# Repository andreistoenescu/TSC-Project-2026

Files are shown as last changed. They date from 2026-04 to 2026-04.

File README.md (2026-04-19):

# Watch_TSC_Project

Un smartwatch construit de la zero — schematic, PCB 4 straturi, carcasă 3D — centrat pe nRF52840 și un display E-Paper care nu consumă energie când nu se schimbă nimic pe ecran.

---

## Ce este acest proiect

Scopul a fost să proiectez un ceas inteligent complet: de la primul simbol în schematic până la modelul 3D gata de imprimat. Nu un modul dev board montat într-o carcasă, ci un PCB custom cu toate componentele alese și integrate manual.

Tehnologia cheie este display-ul **E-Paper (e-ink)** — odată ce afișează ceva, menține imaginea fără niciun consum de curent. Combinat cu modurile deep sleep ale nRF52840 (1.5μA), rezultatul este un dispozitiv care poate rula zile întregi dintr-o celulă LiPo mică.

### Ce integrează placa

| Subsistem | Componentă | Rol |
|---|---|-----|
| Microcontroller | nRF52840 | Cortex-M4 64MHz, BT 5.0, USB nativ |
| Display | E-Paper via SPI | Afișaj zero-consum în standby |
| Mișcare | BMA423 | Accelerometru 3 axe, step counter, wake-on-wrist |
| Încărcare | BQ25180 | LiPo charger programabil I2C, 5mA–1A |
| Alimentare | RT6160 | Buck-Boost 3.3V stabil indiferent de tensiunea bateriei |
| Baterie | MAX17048 | Fuel gauge ModelGauge, fără shunt rezistor |
| Feedback | DRV2605 | Driver haptic, 123 efecte ERM/LRA |
| USB | KH-TYPE-C-16P + USBLC6 | Conector C16P cu protecție ESD ±15kV |
| Input | EVP-AKE31A ×3 | Butoane tactile SMD ultra-subțiri |
| RF | 2450AT18B100E | Antenă SMD 2.45GHz pentru Bluetooth |

---

## Diagrama bloc a sistemului

```
  USB-C (5V)
      │
      ▼
 ┌─────────┐    VBUS      ┌──────────────┐
 │  ESD    │─────────────▶│  BQ25180     │ LiPo Charger
 │USBLC6   │              │  (I2C 0x6A)  │◀─── Baterie LiPo
 └────┬────┘              └──────┬───────┘
      │ D+/D−                    │ VBAT
      │                          ▼
      │                   ┌──────────────┐
      │                   │  MAX17048    │ Fuel Gauge
      │                   │  (I2C 0x36)  │
      │                   └──────┬───────┘
      │                          │ VBAT
      │                          ▼
      │                   ┌──────────────┐
      │                   │   RT6160     │ Buck-Boost DC/DC
      │                   │  (I2C 0x62)  │─── 3V3 ───────────┐
      │                   └──────────────┘                    │
      │                                                       │
      └───────────────────────────────────────────────────────▼
                                                     ┌─────────────────┐
                    ┌── SPI ──▶ E-Paper Display       │                 │
                    │                                 │   nRF52840      │
                    ├── I2C ──▶ BMA423  (0x18)        │   Cortex-M4     │
                    │       ──▶ DRV2605 (0x5A)        │   64MHz / BT5.0 │
                    │       ──▶ BQ25180 (0x6A)        │                 │
                    │       ──▶ RT6160  (0x62)        └────────┬────────┘
                    │       ──▶ MAX17048(0x36)                 │
                    │                                          │ GPIO
                    ├── SWD ──▶ TC2030-IDC                     │
                    │                                          ▼
                    └── USB ──▶ (intern nRF52840)      Butoane ×3 / IMU INT / HAPTIC_EN
```

---

## Componente — BOM complet

| Ref | Part Number | Descriere | Qty |
|-----|---|---|:---:|
| U1 | nRF52840-QIAA | MCU ARM Cortex-M4, BT 5.0, USB 2.0, 1MB Flash | 1 |
| IC1 | BQ25180YBGR | LiPo charger liniar 1A I2C, 8-DSBGA | 1 |
| IC2 | DRV2605YZFR | Haptic driver ERM/LRA I2C 123 efecte, 9-BGA | 1 |
| IC3 | BMA423 | Accelerometru MEMS triaxial 12-bit, LGA-12 | 1 |
| U3 | MAX17048G+T10 | Fuel gauge ModelGauge 1-cell, SOT-23-6 | 1 |
| IC9 | RT6160AWSC | Buck-Boost DC/DC 800mA I2C, 15-WL-CSP | 1 |
| D3 | USBLC6-2SC6Y | TVS ESD ±15kV bidirecțional USB, SOT-23-6 | 1 |
| J4 | KH-TYPE-C-16P | Conector USB-C 16 pini SMD | 1 |
| J1 | 503480-2400 | Conector FPC/FFC 0.5mm pas 24 circuite | 1 |
| J2 | TC2030-IDC | Tag-Connect SWD 6 pini footprint-only | 1 |
| Q2 | DMG2305UX-7 | P-MOSFET 20V/4.2A, SOT-23 | 1 |
| Q3 | SI1308EDL-T1-GE3 | N-MOSFET 30V/1.5A, SC-70 | 1 |
| D1,D2,D5 | MBR0530 | Schottky 30V/500mA, SOD-123 | 3 |
| SW_* | EVP-AKE31A | Buton tactil SMD ultra-subțire Panasonic | 3 |
| ANT1 | 2450AT18B100E | Antenă SMD 2.45GHz Johanson | 1 |
| L7 | FTC252012SR47MBCA | Inductor 0.47μH SMD 2016 | 1 |
| L5 | 744043680 | Inductor 68μH WE-TPC SMD | 1 |
| X1 | Crystal 32MHz | Oscilator SMD 32MHz 2016 | 1 |
| X2 | Crystal 32.768kHz | Oscilator RTC 32.768kHz 3215 SMD | 1 |
| Cx | — | Condensatoare SMD 0201/0402, 1pF–22μF | ~50 |
| Rx | — | Rezistoare SMD 0201, 2.2Ω–10kΩ | ~15 |
| Lx | — | Inductoare SMD 0402, 3.9nH–10μH | ~4 |
| TP_* | TP20R | Test pad SMD 2mm | 14 |
| SJ1 | — | Solder jumper SMD | 1 |

---

## Hardware în detaliu

### Cum circulă energia

Bateria LiPo (3.7–4.2V) alimentează regulatorul **RT6160** care produce un 3V3 stabil pentru toată placa. Când e conectat USB-C, VBUS (5V) merge direct la **BQ25180** care preia încărcarea bateriei independent de restul sistemului. nRF52840 monitorizează ambele stări: știe când USB e prezent (CHARGER_PG) și câtă baterie a mai rămas (MAX17048 via I2C).

Componentele cu consum ridicat — display-ul și haptic driver-ul — sunt controlate prin MOSFET-uri (Q2/Q3), astfel că nRF52840 le poate tăia complet alimentarea când nu sunt necesare.

### Magistrala I2C — 5 periferice pe aceleași fire

| Componentă | Adresă I2C | Ce face |
|---|:---:|---|
| BQ25180 | 0x6A | Controlează curentul și tensiunea de încărcare |
| RT6160 | 0x62 | Ajustează tensiunea de ieșire dacă e necesar |
| BMA423 | 0x18 | Livrează date accelerometru, numără pași |
| MAX17048 | 0x36 | Raportează SOC% și tensiunea celulei |
| DRV2605 | 0x5A | Selectează și redă efecte tactile |

Clock pe **P0.06**, date pe **P0.07**. Rezistoare de pull-up pe ambele linii.

### SPI — display E-Paper

Comunicație write-only spre display (nu există linie MISO — displayul nu trimite date înapoi). Frecvență maximă 4MHz. Pe lângă SCK și MOSI, display-ul are nevoie de 3 semnale GPIO suplimentare: DC (Data/Command), RST (reset hardware) și BUSY (ceasul trebuie să aștepte când displayul procesează un refresh).

### SWD — programare și debug

Conectorul **TC2030-IDC** (Tag-Connect, fără pini fizici pe PCB) expune SWDIO, SWDCLK, SWO și RESET. Nu ocupă spațiu vertical în ansamblu — cablul de programare se atașează temporar prin spring pins direct pe pad-urile de pe PCB.

### Bluetooth și antena

Antena **2450AT18B100E** este o antenă SMD ceramică pentru 2.4GHz, plasată în colțul plăcii cu un cutout în substrat sub ea. Cutout-ul elimină FR4-ul (material dielelectric cu pierderi la 2.4GHz) din zona de radiație, îmbunătățind câștigul și SWR-ul antenei. Cristalul de 32MHz asigură referința de frecvență pentru radio.

### Cristalul de 32.768kHz — RTC în sleep

Al doilea oscilator, la 32.768kHz, alimentează timer-ul RTC al nRF52840 și rămâne activ chiar și în deep sleep. Permite ceasului să știe ora exactă și să se trezească la intervale precise fără să țină procesorul pornit.

### BMA423 — mai mult decât un accelerometru

BMA423 are un procesor intern dedicat care rulează algoritmii de step counting și wake-on-wrist fără să implice nRF52840. Când detectează mișcarea caracteristică ridicării mâinii, trimite o întrerupere pe **P1.08 (IMU_INT1)** care trezește MCU-ul din deep sleep în microsecunde. Consum în această stare: **0.9μA**.

### Estimare consum și autonomie

| Scenariu | Curent estimat |
|---|:---:|
| nRF52840 TX Bluetooth activ | 6.26 mA |
| nRF52840 RX Bluetooth activ | 4.82 mA |
| Refresh display E-Paper | ~26 mA (câteva secunde) |
| BMA423 monitorizare continuă | 130 μA |
| MAX17048 fuel gauge activ | 23 μA |
| DRV2605 vibrație activă | 5 mA |
| nRF52840 deep sleep + RTC + BMA low-power | ~50–100 μA |

**Consum mediu în utilizare normală** (BT conectat periodic, display refresh la fiecare minut, IMU activ): **6–8 mA** la 3.3V.

Cu o baterie LiPo de **300mAh**: autonomie estimată **35–50 ore**.

---

## Alocarea pinilor nRF52840

### Display E-Paper (SPI)

| Pin MCU | Semnal | Direcție | Descriere |
|---|---|:---:|---|
| P0.02 / AIN0 | SCK | OUT | Clock SPI pentru display |
| P0.03 / AIN1 | MOSI | OUT | Date seriale spre display |
| P0.05 / AIN3 | EPD_CS | OUT | Chip select, activ LOW |
| P0.15 | EPD_RST | OUT | Reset hardware display, activ LOW |
| P0.16 | EPD_DC | OUT | LOW = comandă, HIGH = date |
| P0.17 | EPD_BUSY | IN | HIGH când displayul procesează |

### Periferice I2C

| Pin MCU | Semnal | Descriere |
|---|---|---|
| P0.06 | SCL | Clock comun pentru toate perifericele I2C |
| P0.07 | SDA | Date bidirecționale I2C |
| P0.08 | IMU_INT2 | Întrerupere secundară BMA423 (step counter) |
| P1.08 | IMU_INT1 | Întrerupere primară BMA423 (wake-on-wrist) |
| P0.10 / NFC2 | FUELGAUGE_ALT | Alarmă MAX17048 la baterie scăzută |
| P0.11 | CHARGER_PG | Power Good BQ25180 — 1 când USB e valid |
| P0.12 | HAPTIC_EN | Enable DRV2605, activ HIGH |

### Butoane și control

| Pin MCU | Semnal | Descriere |
|---|---|---|
| P0.13 | BTN_UP | Buton sus (navigare meniu) |
| P0.14 | BTN_ENT | Buton enter / confirmare |
| P1.02 | BTN_DN | Buton jos (navigare meniu) |

### USB, SWD și ceasuri

| Pin MCU | Semnal | Interfață | Descriere |
|---|---|:---:|---|
| D+ | USB_DP | USB | Linie diferențială pozitivă, prin ESD |
| D− | USB_DM | USB | Linie diferențială negativă, prin ESD |
| VBUS | 5V_USB | PWR | Detecție USB prezent → BQ25180 |
| SWDIO | SWDIO | SWD | Date programare/debug |
| SWDCLK | SWDCLK | SWD | Clock programare/debug |
| SWO | SWO | SWD | Serial Wire Output (trace) |
| P0.18 / RESET | RESET | GPIO | Reset hardware MCU |
| ANT | RF | RF | Antenă Bluetooth 2.4GHz |
| XC1, XC2 | XTAL_32M | CLK | Cristal 32MHz — clock principal |
| XL1, XL2 | XTAL_32K | CLK | Cristal 32.768kHz — RTC sleep |

---

## PCB — decizii de proiectare

### 4 straturi: de ce și cum

| Strat | Conținut |
|---|---|
| **L1 — Top** | Toate componentele SMD + rutare semnale principale |
| **L2** | Plan de masă GND continuu |
| **L3** | Plan de alimentare 3V3 |
| **L4 — Bottom** | Rutare secundară + via connections |

Planul de masă pe L2 direct sub stratul de semnal L1 minimizează inductanța buclei de return pentru fiecare traseu. Fără acest plan, semnalele SPI și I2C ar genera mai mult EMI și ar fi mai sensibile la zgomot. Planul de 3V3 pe L3 reduce impedanța de alimentare, esențial pentru vârfurile de curent ale nRF52840 în TX.

### Via-in-pad

BQ25180, RT6160, DRV2605 și MAX17048 vin în packaging BGA/CSP cu pitch sub 0.5mm — imposibil de rutat cu via-uri laterale în spațiul disponibil. Soluția: via-uri plasate direct în centrul pad-urilor BGA. Acestea trebuie **umplute cu rășină epoxidică și planarize** (filled & capped) înainte de HASL/ENIG, altfel pasta de lipit curge în via și jointul devine defectuos.

### Cutout sub antenă

Substatul FR4 este un material cu pierderi dielectrice la 2.4GHz. Lăsat sub zona de radiație a antenei 2450AT18B100E, absoarbe o parte din energia RF și detune antena față de 50Ω. Soluția: un decupaj fizic al PCB-ului sub jumătatea neconectată a antenei, astfel că aceasta radiază în aer.

### 14 test pad-uri TP20R

Distribuite pe semnalele: 3V3, VBAT, GND, SDA, SCL, SWDCLK, SWDIO, SWO, RESET, VREG. Permit conectarea unui multimetru sau logicanalyzer după asamblare fără a fi nevoie de probe pe QFN/BGA.

---

## Ansamblu 3D

Modelat complet în **Autodesk Fusion 360**. Ansamblul verifică că totul se potrivește fizic înainte de fabricație.

Stratificarea de jos în sus:

```
  ┌─────────────────────────┐  ← Cadru superior + geam display
  │     Display E-Paper     │  ← Panou e-ink + cablu FPC
  │         PCB             │  ← Placa cu toate componentele
  │      Baterie LiPo       │  ← Celulă cu fire sudate pe test pads
  └─────────────────────────┘  ← Carcasă inferioară
```

Butoanele (×3) sunt accesibile prin locașuri în carcasa inferioară, pe laterale. Conectorul USB-C iese prin fanta frontală a carcasei. Shaker-ul haptic este montat cilindric în spațiul rămas lângă baterie.

---

## Galerie

### PCB — Layout 2D
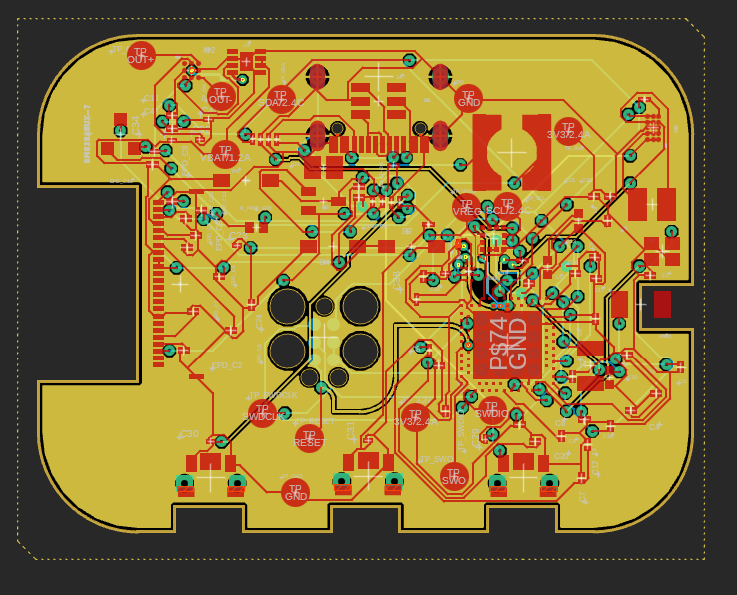
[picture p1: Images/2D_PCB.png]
PCB 2D


### PCB — Randare 3D
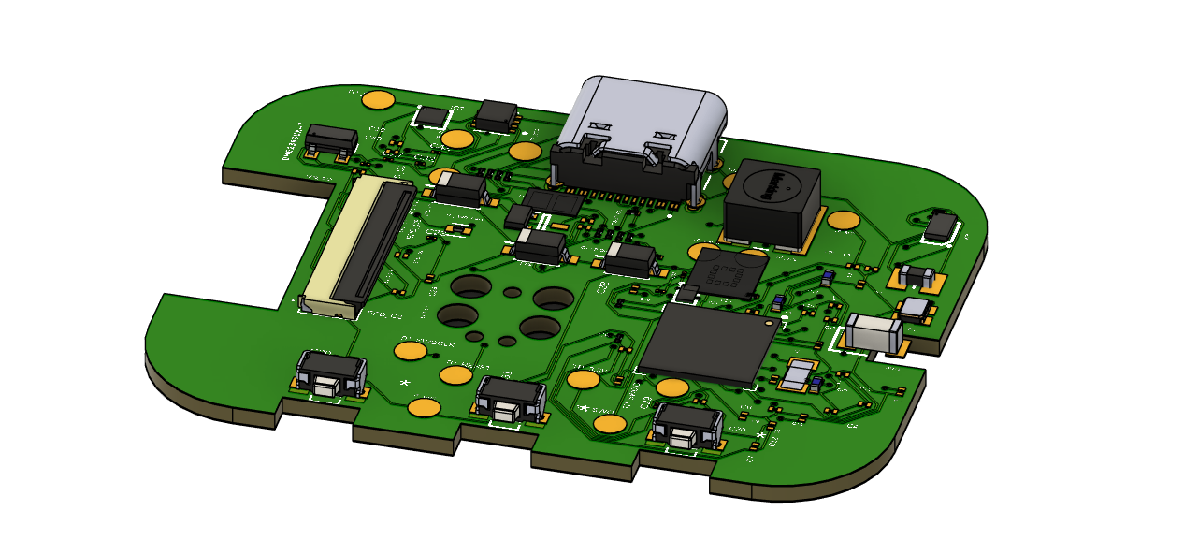
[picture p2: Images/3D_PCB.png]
PCB 3D


### Ceas asamblat
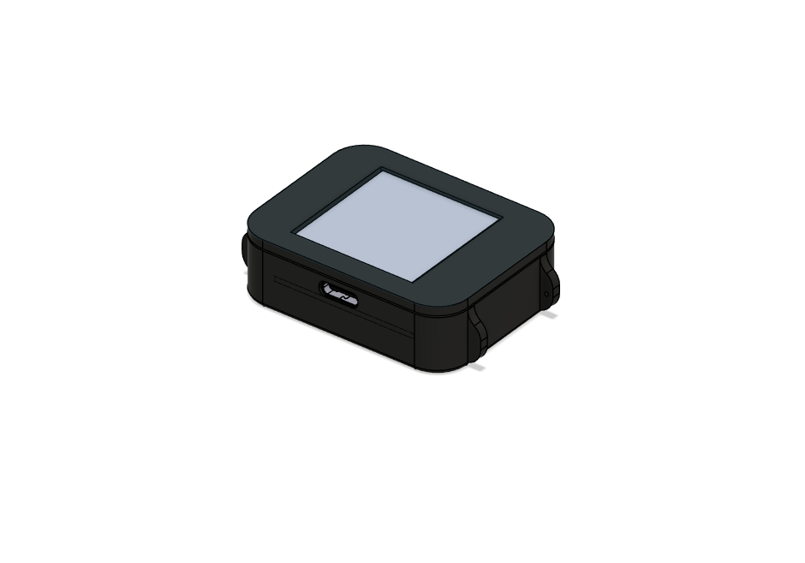
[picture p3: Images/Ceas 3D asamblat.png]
Ceas asamblat


### Exploded View
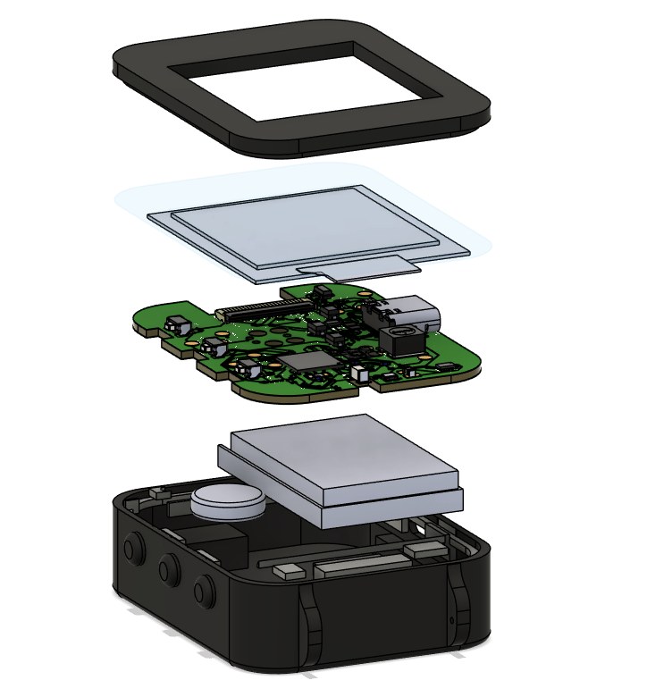
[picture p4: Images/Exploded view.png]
Exploded View


### Baterie LiPo
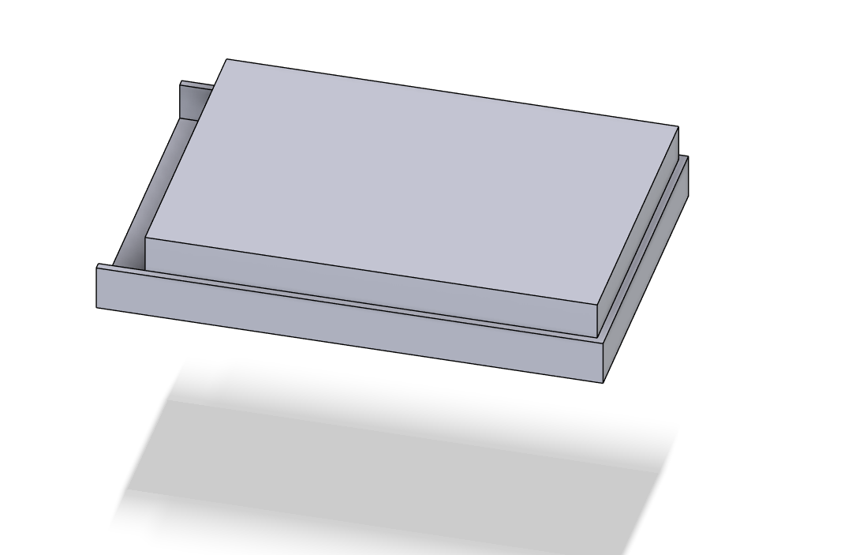
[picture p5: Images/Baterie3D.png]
Baterie


### Display E-Paper
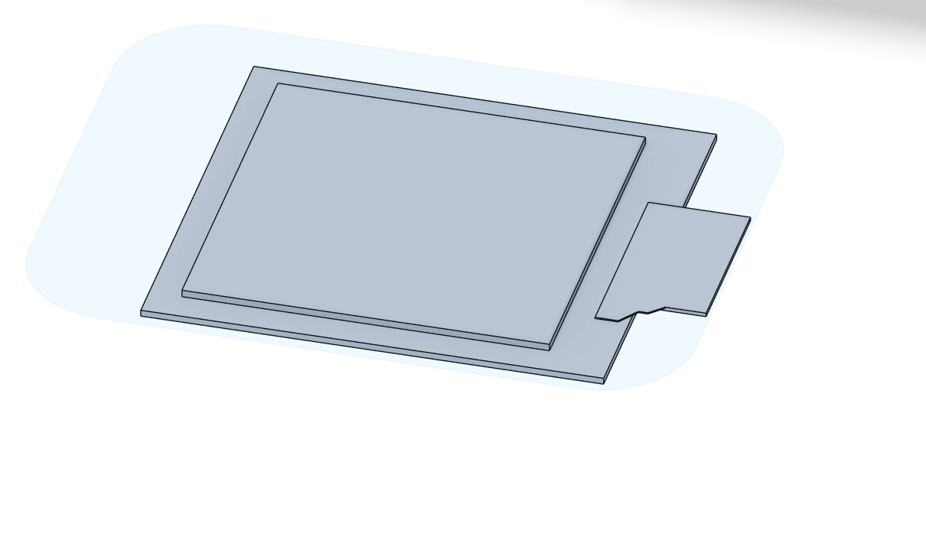
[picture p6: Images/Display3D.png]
Display


### Motor Haptic
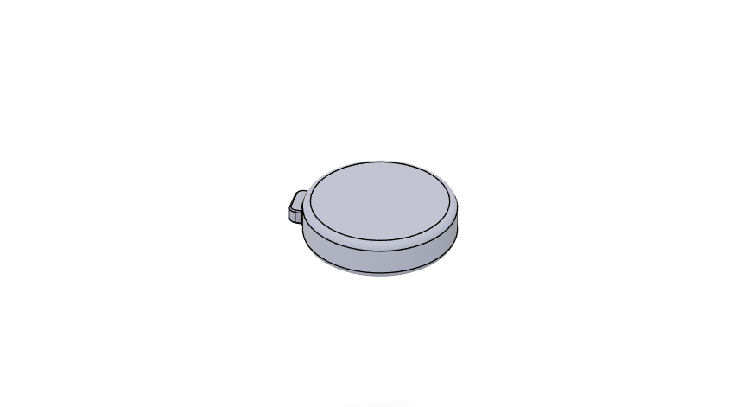
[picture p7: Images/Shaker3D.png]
Shaker


---

## Structura repository-ului

```
Watch_TSC_Project/
│
├── Hardware/
│   ├── PCB_2D.brd              # Fișier board KiCad/Eagle
│   ├── Schematic_final.sch     # Schematic complet
│   └── Schematic_final.pdf     # Export PDF schematic
│
├── Manufacturing/
│   ├── gerbers.zip             # Fișiere Gerber pentru fabricație PCB
│   ├── Watch_TSC_bom.bom       # Bill of Materials pentru comandă componente
│   ├── PnP_Watch_TSC_front.cpl # Pick & Place față
│   └── PnP_Watch_TSC_back.cpl  # Pick & Place spate
│
├── Mechanical/
│   ├── Exploded_Watch_3D.zip   # Export STEP ansamblu exploded
│   └── Watch_3D.f3z            # Proiect Autodesk Fusion 360
│
├── Images/                     # Randări și capturi PCB
│
├── LICENSE
└── README.md
```

---

MIT License — Copyright 2026 Stoenescu Constantin-Andrei

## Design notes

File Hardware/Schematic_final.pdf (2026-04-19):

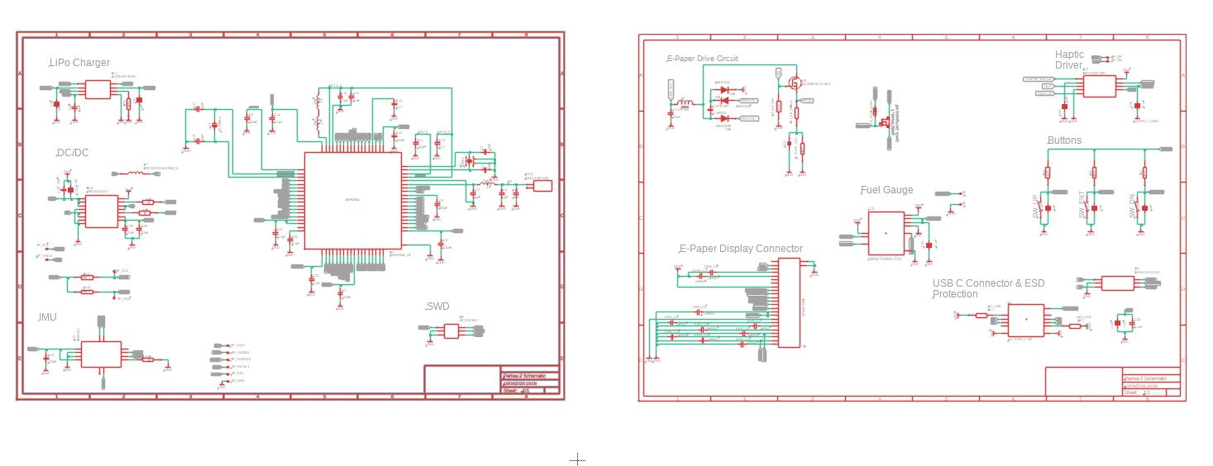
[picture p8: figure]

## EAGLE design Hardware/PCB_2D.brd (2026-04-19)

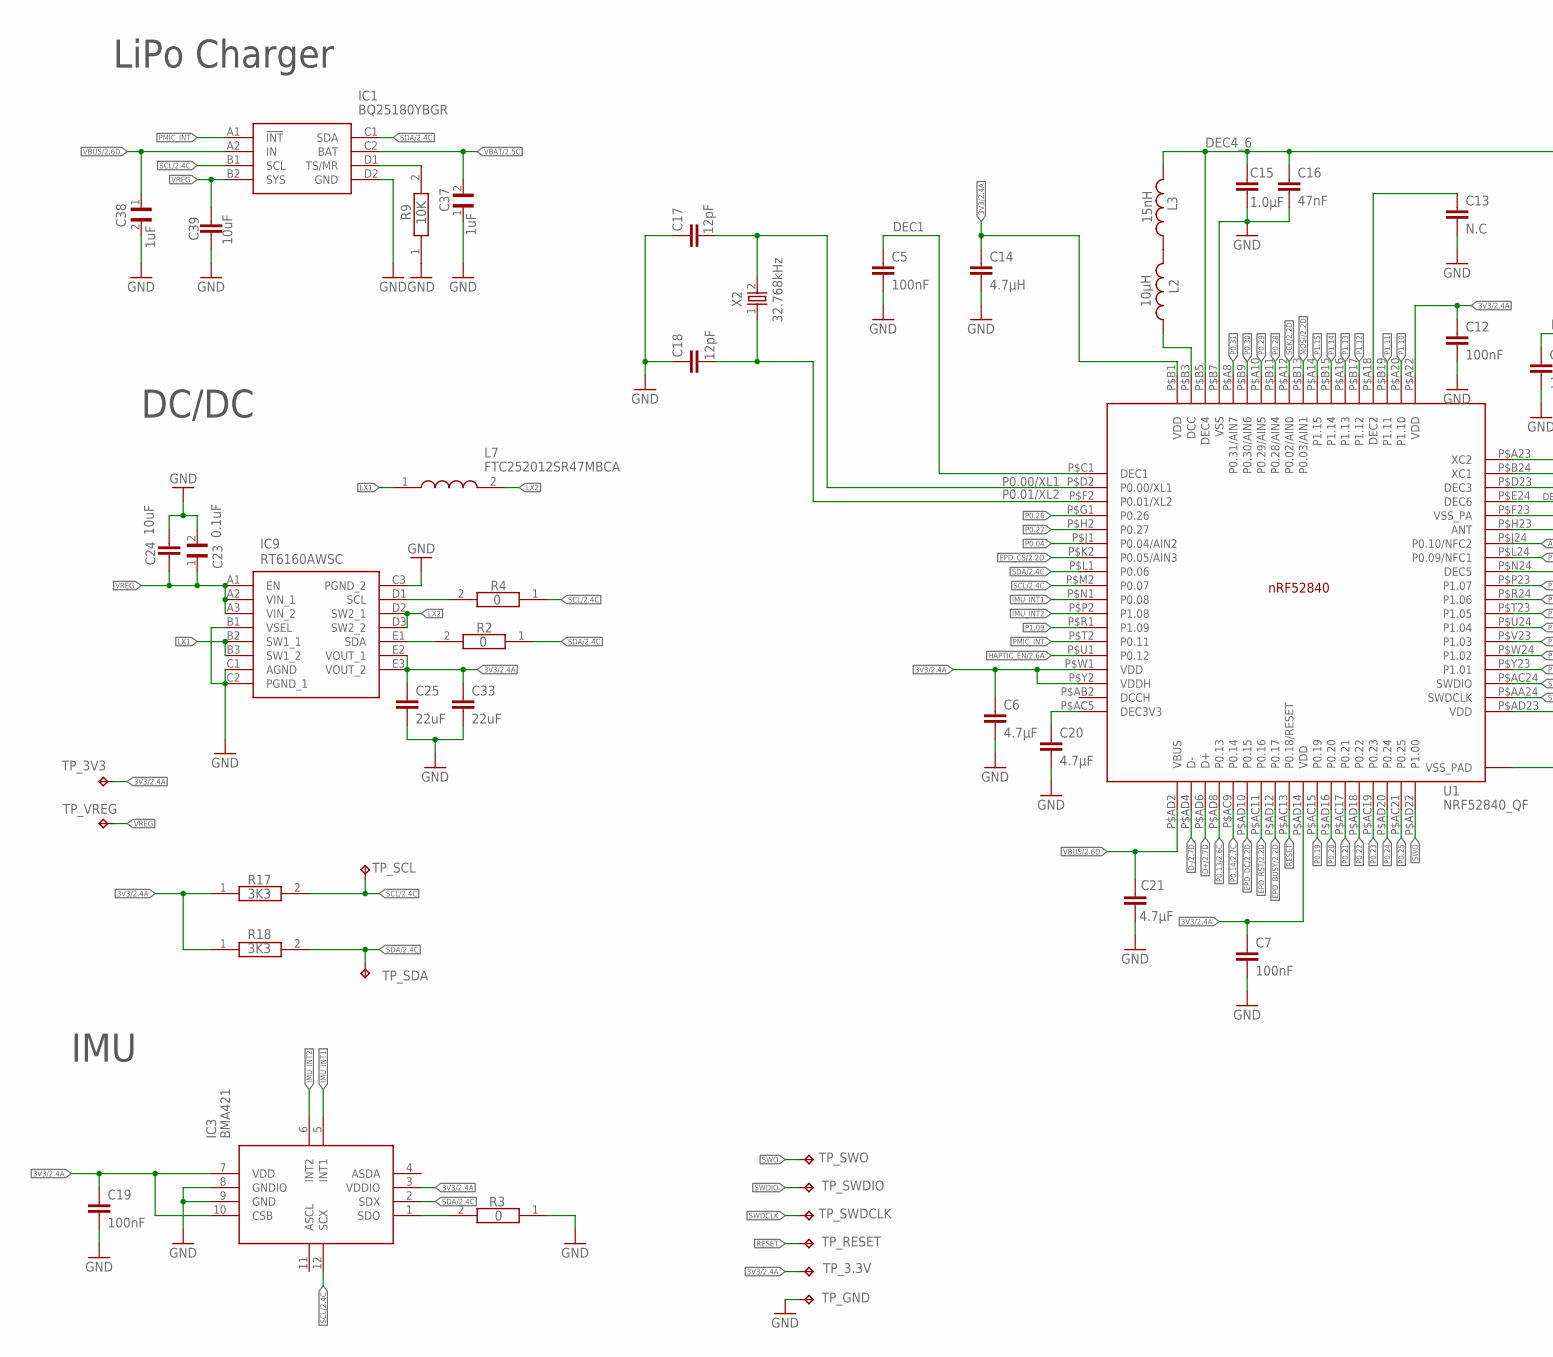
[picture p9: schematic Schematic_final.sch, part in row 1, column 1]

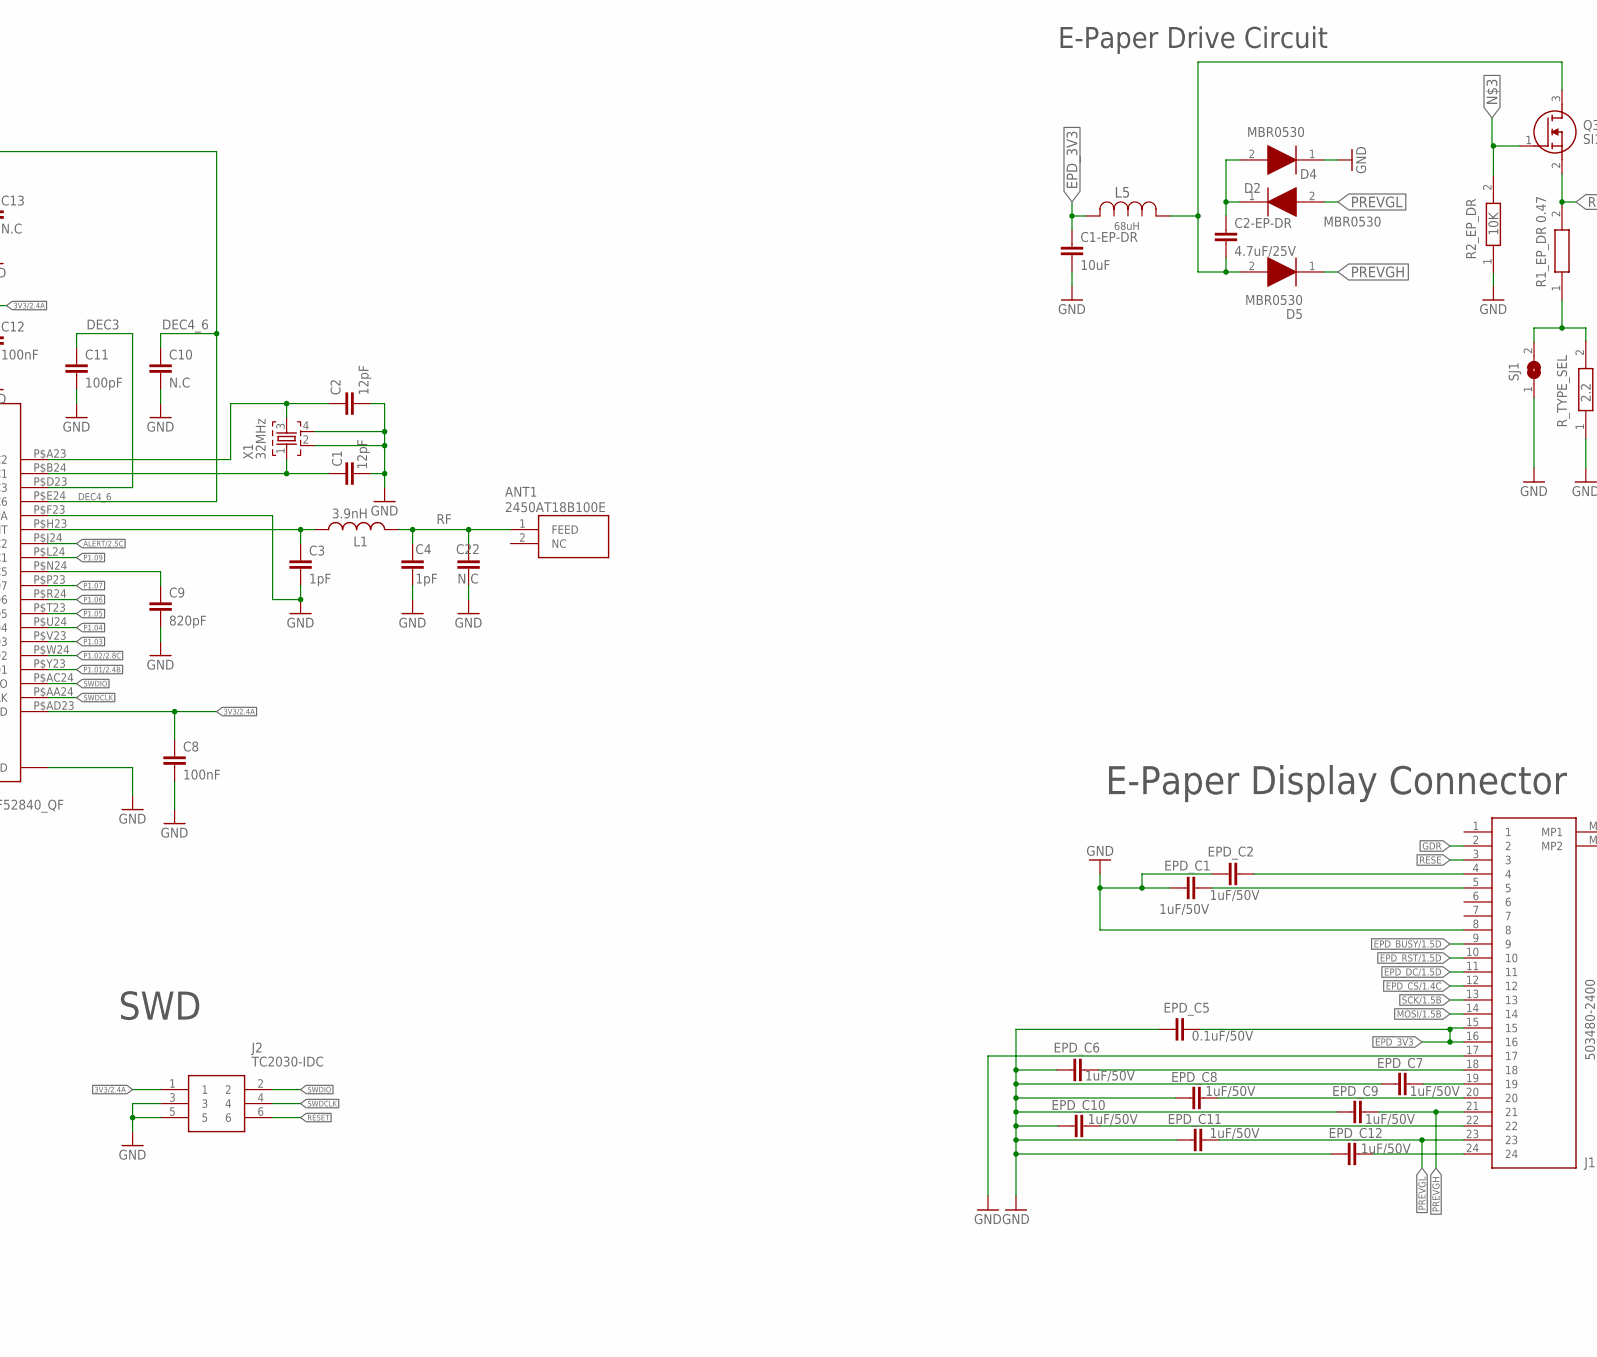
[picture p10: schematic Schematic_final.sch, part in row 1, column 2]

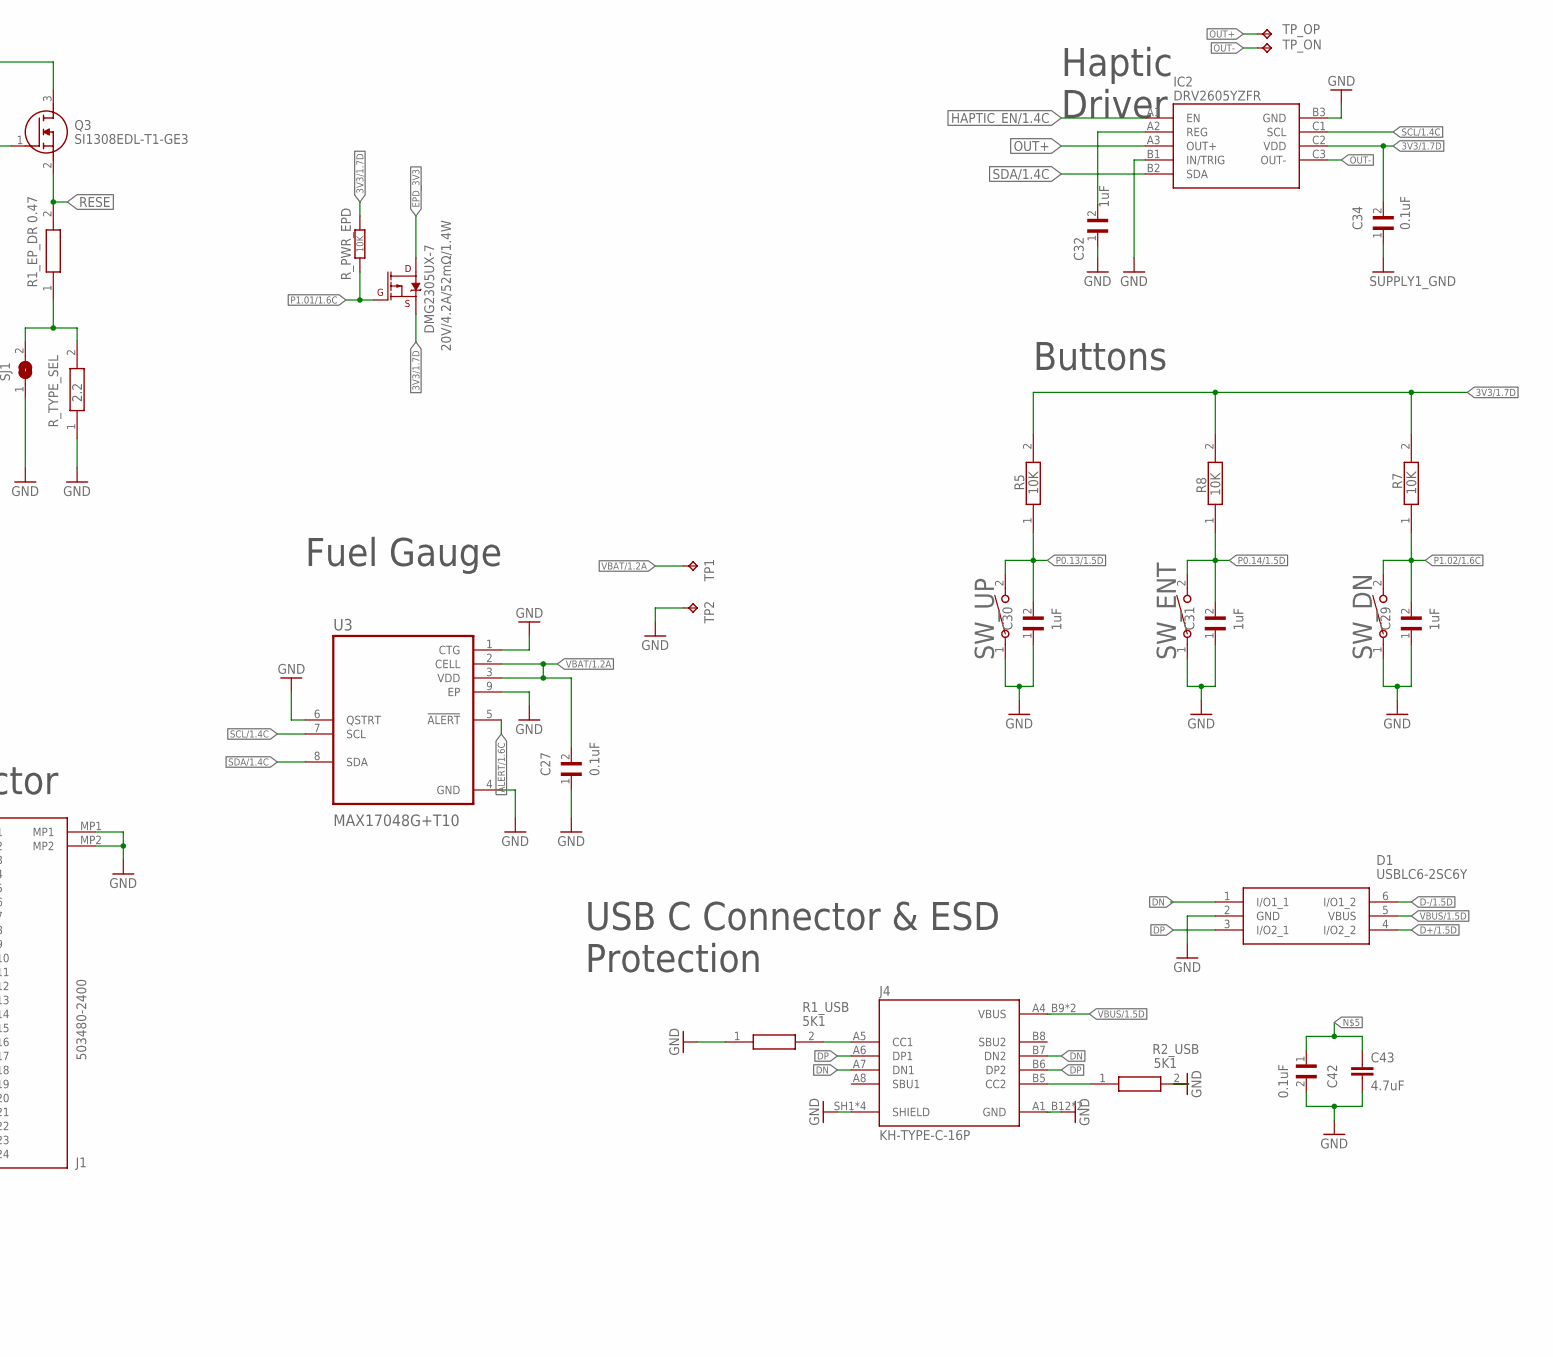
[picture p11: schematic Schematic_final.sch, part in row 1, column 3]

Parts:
ANT1: 2450AT18B100E; 2450AT18B100E_ANTC3216X140N
C1, C2, C17, C18: 12pF; NORDIC_NRF_3_RESC0201_L
C1-EP-DR, C24, C39: 10uF; NORDIC_NRF_3_RESC0201_L
C2-EP-DR: 4.7uF/25V; NORDIC_NRF_3_RESC0201_L
C3, C4: 1pF; NORDIC_NRF_3_RESC0201_L
C5, C7, C8, C12, C19: 100nF; NORDIC_NRF_3_RESC0201_L
C6, C20, C21: 4.7μF; NORDIC_NRF_3_RESC0201_L
C9: 820pF; NORDIC_NRF_3_RESC0201_L
C10, C13, C22: N.C; NORDIC_NRF_3_RESC0201_L
C11: 100pF; NORDIC_NRF_3_RESC0201_L
C14: 4.7μH; NORDIC_NRF_3_RESC0201_L
C15: 1.0μF; NORDIC_NRF_3_RESC0201_L
C16: 47nF; NORDIC_NRF_3_RESC0201_L
C23, C27, C34, C42: 0.1uF; GRM011R60J152KE01L_2_CAPC0201X13N
C25, C33: 22uF; NORDIC_NRF_3_RESC0201_L
C29, C30, C31, C32, C37, C38: 1uF; GRM011R60J152KE01L_2_CAPC0201X13N
C43: 4.7uF; NORDIC_NRF_3_RESC0201_L
D1: USBLC6-2SC6Y; ESP32_C6_LIBRARY_3_SOT95P280X145-6N
D2, D4, D5: MBR0530; ESP32_C6_LIBRARY_5_SOD3716X135N
DMG2305UX-7: 20V/4.2A/52mΩ/1.4W; ESP32_C6_LIBRARY_4_ESP32_C6_LIBRARY_4_ESP32_C6_LIBRARY_4_ES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
EPD_C1, EPD_C2, EPD_C6, EPD_C7, EPD_C8, EPD_C9, EPD_C10, EPD_C11, EPD_C12: 1uF/50V; NORDIC_NRF_3_RESC0201_L
EPD_C5: 0.1uF/50V; NORDIC_NRF_3_RESC0201_L
IC1: BQ25180YBGR; BQ25180YBGR_BGA8C40P2X4_100X155X50
IC2: DRV2605YZFR; DRV2605YZFR_BGA9C50P3X3_144X144X62
IC3: BMA421; BMA423_BMA423
IC9: RT6160AWSC; RT6160AWSC_BGA15C40P3X5_140X230X60
J1: 503480-2400; 503480-2400_5034802400
J2: TC2030-IDC; TC2030-IDC_TC2030IDC
J4: KH-TYPE-C-16P; KH-TYPE-C-16P_KINGHELM_KH-TYPE-C-16P
L1: 3.9nH; NORDIC_NRF_2_RESC0402_L
L2: 10μH; NORDIC_NRF_2_RESC0402_L
L3: 15nH; NORDIC_NRF_2_RESC0402_L
L5: 68uH; ESP32_C6_LIBRARY_2_IND_4828-WE-TPC_WRE
L7: FTC252012SR47MBCA; MLP2016SR47MT0S1_INDC2016X100N
Q3: SI1308EDL-T1-GE3; ESP32_C6_LIBRARY_6_SOT65P210X110-3N
R1_EP_DR: 0.47; CPF0201D7K68C1_0201
R1_USB, R2_USB: 5K1; CPF0201D7K68C1_0201
R2, R3, R4: 0; CPF0201D7K68C1_0201
R2_EP_DR, R5, R7, R8, R9: 10K; CPF0201D7K68C1_0201
R17, R18: 3K3; CPF0201D7K68C1_0201
R_PWR_EPD: 10K; RESC1005X40
R_TYPE_SEL: 2.2; CPF0201D7K68C1_0201
SJ1: ESP32_C6_LIBRARY_7_JUMPER_SJ
SW_DN: 2025-10-22_07-23-44_LIBRARY_EVP-AKE31ASW_EVP-AKE3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; 2025-10-22_07-23-44_LIBRARY_SW_EVP-AKE31A_PAN
SW_ENT: 2025-10-22_07-23-44_LIBRARY_EVP-AKE31ASW_EVP-AKE3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; 2025-10-22_07-23-44_LIBRARY_SW_EVP-AKE31A_PAN
SW_UP: 2025-10-22_07-23-44_LIBRARY_EVP-AKE31ASW_EVP-AKE3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; 2025-10-22_07-23-44_LIBRARY_SW_EVP-AKE31A_PAN
TP1, TP2: HECTOR_WATCH_1_TPTP20R; HECTOR_WATCH_1_TP20R
TP_3.3V, TP_3V3: HECTOR_WATCH_1_TPTP20R; HECTOR_WATCH_1_TP20R
TP_GND: HECTOR_WATCH_1_TPTP20R; HECTOR_WATCH_1_TP20R
TP_ON: HECTOR_WATCH_1_TPTP20R; HECTOR_WATCH_1_TP20R
TP_OP: TP_OP; HECTOR_WATCH_1_TP20R
TP_RESET: HECTOR_WATCH_1_TPTP20R; HECTOR_WATCH_1_TP20R
TP_SCL: HECTOR_WATCH_1_TPTP20R; HECTOR_WATCH_1_TP20R
TP_SDA: HECTOR_WATCH_1_TPTP20R; HECTOR_WATCH_1_TP20R
TP_SWDCLK: HECTOR_WATCH_1_TPTP20R; HECTOR_WATCH_1_TP20R
TP_SWDIO: HECTOR_WATCH_1_TPTP20R; HECTOR_WATCH_1_TP20R
TP_SWO: HECTOR_WATCH_1_TPTP20R; HECTOR_WATCH_1_TP20R
TP_VREG: HECTOR_WATCH_1_TPTP20R; HECTOR_WATCH_1_TP20R
U1: NRF52840_QF; NORDIC_NRF_4_AQFN50P700X700X85_HS-74N
U3: MAX17048G+T10; ESP32_C6_LIBRARY_SON50P200X200X80-9N
X1: 32MHz; NORDIC_NRF_BT-XTAL_2016_N
X2: 32.768kHz; NORDIC_NRF_1_XTAL_3215_N

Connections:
3V3/1.7D: C34.2, DMG2305UX-7.2 (S), IC2.C2 (VDD), R5.2, R7.2, R8.2, R_PWR_EPD.2
3V3/2.4A: C6.1, C7.1, C8.1, C12.1, C14.1, C19.1, C25.1, C33.1, IC3.3 (VDDIO), IC3.7 (VDD), IC3.10 (CSB), IC9.E2 (VOUT_1), IC9.E3 (VOUT_2), J2.1, R17.1, R18.1, TP_3.3V.TP, TP_3V3.TP, U1.P$A22 (VDD), U1.P$AD14 (VDD), U1.P$AD23 (VDD), U1.P$B1 (VDD), U1.P$W1 (VDD), U1.P$Y2 (VDDH)
ALERT/1.6C: U3.5 (!ALERT)
ALERT/2.5C: U1.P$J24 (P0.10/NFC2)
D+/1.5D: D1.4 (I/O2_2)
D+/2.7D: U1.P$AD6 (D+)
D-/1.5D: D1.6 (I/O1_2)
D-/2.7D: U1.P$AD4 (D-)
DEC1: C5.1, U1.P$C1 (DEC1)
DEC3: C11.1, U1.P$D23 (DEC3)
DEC4_6: C10.1, C15.1, C16.1, L3.2, U1.P$B5 (DEC4), U1.P$E24 (DEC6)
DN: D1.1 (I/O1_1), J4.A7 (DN1), J4.B7 (DN2)
DP: D1.3 (I/O2_1), J4.A6 (DP1), J4.B6 (DP2)
EPD_3V3: C1-EP-DR.1, DMG2305UX-7.3 (D), EPD_C5.2, J1.15, J1.16, L5.2
EPD_BUSY/1.5D: J1.9
EPD_BUSY/2.2D: U1.P$AD12 (P0.17)
EPD_CS/1.4C: J1.12
EPD_CS/2.2D: U1.P$K2 (P0.05/AIN3)
EPD_DC/1.5D: J1.11
EPD_DC/2.2D: U1.P$AD10 (P0.15)
EPD_RST/1.5D: J1.10
EPD_RST/2.2D: U1.P$AC11 (P0.16)
GDR: J1.2
GND: C1.2, C1-EP-DR.2, C2.2, C3.2, C4.2, C5.2, C6.2, C7.2, C8.2, C9.2, C10.2, C11.2, C12.2, C13.2, C14.2, C15.2, C16.2, C17.1, C18.1, C19.2, C20.2, C21.2, C22.2, C23.2, C24.1, C25.2, C27.1, C29.1, C30.1, C31.1, C32.1, C33.2, C34.1, C37.1, C38.2, C39.2, C42.2, C43.2, D1.2 (GND), D4.1 (K), EPD_C1.1, EPD_C2.1, EPD_C5.1, EPD_C6.1, EPD_C7.1, EPD_C8.1, EPD_C9.1, EPD_C10.1, EPD_C11.1, EPD_C12.1, IC1.D2 (GND), IC2.B1 (IN/TRIG), IC2.B3 (GND), IC3.8 (GNDIO), IC3.9 (GND), IC9.B1 (VSEL), IC9.C1 (AGND), IC9.C2 (PGND_1), IC9.C3 (PGND_2), J1.8, J1.17, J1.MP1, J1.MP2, J2.3, J2.5, J4.A1_B12 (GND), J4.A12_B1 (GND), J4.SH1 (SHIELD), J4.SH2 (SHIELD), J4.SH3 (SHIELD), J4.SH4 (SHIELD), R1_USB.1, R2_EP_DR.1, R2_USB.2, R3.1, R9.1, R_TYPE_SEL.1, SJ1.1, SW_DN.1, SW_ENT.1, SW_UP.1, TP2.TP, TP_GND.TP, U1.P$74 (VSS_PAD), U1.P$75 (VSS_PAD), U1.P$76 (VSS_PAD), U1.P$77 (VSS_PAD), U1.P$78 (VSS_PAD), U1.P$79 (VSS_PAD), U1.P$80 (VSS_PAD), U1.P$81 (VSS_PAD), U1.P$82 (VSS_PAD), U1.P$83 (VSS_PAD), U1.P$84 (VSS_PAD), U1.P$85 (VSS_PAD), U1.P$86 (VSS_PAD), U1.P$87 (VSS_PAD), U1.P$88 (VSS_PAD), U1.P$89 (VSS_PAD), U1.P$90 (VSS_PAD), U1.P$B7 (VSS), U1.P$F23 (VSS_PA), U3.1 (CTG), U3.4 (GND), U3.6 (QSTRT), U3.9 (EP), X1.2, X1.4
HAPTIC_EN/1.4C: IC2.A1 (EN)
HAPTIC_EN/2.6A: U1.P$U1 (P0.12)
IMU_INT1: IC3.5 (INT1), U1.P$N1 (P0.08)
IMU_INT2: IC3.6 (INT2), U1.P$P2 (P1.08)
LX1: IC9.B2 (SW1_1), IC9.B3 (SW1_2), L7.1
LX2: IC9.D2 (SW2_1), IC9.D3 (SW2_2), L7.2
MOSI/1.5B: J1.14
MOSI/2.2D: U1.P$B13 (P0.03/AIN1)
unnamed: C2-EP-DR.2, D5.2 (A), L5.1, Q3.3 (D)
unnamed: C2-EP-DR.1, D2.1 (K), D4.2 (A)
unnamed: Q3.1 (G), R2_EP_DR.2
unnamed: R1_EP_DR.1, R_TYPE_SEL.2, SJ1.2
unnamed: C42.1, C43.1
unnamed: C32.2, IC2.A2 (REG)
unnamed: IC1.D1 (TS/MR), R9.2
unnamed: J4.A5 (CC1), R1_USB.2
unnamed: IC3.1 (SDO), R3.2
unnamed: EPD_C2.2, J1.4
unnamed: EPD_C1.2, J1.5
unnamed: IC9.D1 (SCL), R4.2
unnamed: IC9.E1 (SDA), R2.2
unnamed: J4.B5 (CC2), R2_USB.1
unnamed: C20.1, U1.P$AC5 (DEC3V3)
unnamed: EPD_C6.2, J1.18
unnamed: EPD_C7.2, J1.19
unnamed: EPD_C8.2, J1.20
unnamed: EPD_C10.2, J1.22
unnamed: EPD_C12.2, J1.24
unnamed: C9.1, U1.P$N24 (DEC5)
unnamed: C3.1, L1.1, U1.P$H23 (ANT)
unnamed: C2.1, U1.P$A23 (XC2), X1.3
unnamed: C1.1, U1.P$B24 (XC1), X1.1
unnamed: C13.1, U1.P$A18 (DEC2)
unnamed: L2.1, U1.P$B3 (DCC)
unnamed: L2.2, L3.1
OUT+: IC2.A3 (OUT+), TP_OP.TP
OUT-: IC2.C3 (OUT-), TP_ON.TP
P0.00/XL1: C17.2, U1.P$D2 (P0.00/XL1), X2.2
P0.01/XL2: C18.2, U1.P$F2 (P0.01/XL2), X2.1
P0.04: U1.P$J1 (P0.04/AIN2)
P0.13/1.5D: C30.2, R5.1, SW_UP.2
P0.13/2.6C: U1.P$AD8 (P0.13)
P0.14/1.5D: C31.2, R8.1, SW_ENT.2
P0.14/2.7C: U1.P$AC9 (P0.14)
P0.19: U1.P$AC15 (P0.19)
P0.20: U1.P$AD16 (P0.20)
P0.21: U1.P$AC17 (P0.21)
P0.22: U1.P$AD18 (P0.22)
P0.23: U1.P$AC19 (P0.23)
P0.24: U1.P$AD20 (P0.24)
P0.25: U1.P$AC21 (P0.25)
P0.26: U1.P$G1 (P0.26)
P0.27: U1.P$H2 (P0.27)
P0.28: U1.P$B11 (P0.28/AIN4)
P0.29: U1.P$A10 (P0.29/AIN5)
P0.30: U1.P$B9 (P0.30/AIN6)
P0.31: U1.P$A8 (P0.31/AIN7)
P1.01/1.6C: DMG2305UX-7.1 (G), R_PWR_EPD.1
P1.01/2.4B: U1.P$Y23 (P1.01)
P1.02/1.6C: C29.2, R7.1, SW_DN.2
P1.02/2.8C: U1.P$W24 (P1.02)
P1.03: U1.P$V23 (P1.03)
P1.04: U1.P$U24 (P1.04)
P1.05: U1.P$T23 (P1.05)
P1.06: U1.P$R24 (P1.06)
P1.07: U1.P$P23 (P1.07)
P1.09: U1.P$L24 (P0.09/NFC1), U1.P$R1 (P1.09)
P1.10: U1.P$A20 (P1.10)
P1.11: U1.P$B19 (P1.11)
P1.12: U1.P$B17 (P1.12)
P1.13: U1.P$A16 (P1.13)
P1.14: U1.P$B15 (P1.14)
P1.15: U1.P$A14 (P1.15)
PMIC_INT: IC1.A1 (!INT), U1.P$T2 (P0.11)
PREVGH: D5.1 (K), EPD_C9.2, J1.21
PREVGL: D2.2 (A), EPD_C11.2, J1.23
RESE: J1.3, Q3.2 (S), R1_EP_DR.2
RESET: J2.6, TP_RESET.TP, U1.P$AC13 (P0.18/RESET)
RF: ANT1.1 (FEED), C4.1, C22.1, L1.2
SCK/1.5B: J1.13
SCK/2.2D: U1.P$A12 (P0.02/AIN0)
SCL/1.4C: IC2.C1 (SCL), U3.7 (SCL)
SCL/2.4C: IC1.B1 (SCL), IC3.12 (SCX), R4.1, R17.2, TP_SCL.TP, U1.P$M2 (P0.07)
SDA/1.4C: IC2.B2 (SDA), U3.8 (SDA)
SDA/2.4C: IC1.C1 (SDA), IC3.2 (SDX), R2.1, R18.2, TP_SDA.TP, U1.P$L1 (P0.06)
SWDCLK: J2.4, TP_SWDCLK.TP, U1.P$AA24 (SWDCLK)
SWDIO: J2.2, TP_SWDIO.TP, U1.P$AC24 (SWDIO)
SWO: TP_SWO.TP, U1.P$AD22 (P1.00)
VBAT/1.2A: C27.2, TP1.TP, U3.2 (CELL), U3.3 (VDD)
VBAT/2.5C: C37.2, IC1.C2 (BAT)
VBUS/1.5D: D1.5 (VBUS), J4.A4_B9 (VBUS), J4.A9_B4 (VBUS)
VBUS/2.6D: C21.1, C38.1, IC1.A2 (IN), U1.P$AD2 (VBUS)
VREG: C23.1, C24.2, C39.1, IC1.B2 (SYS), IC9.A1 (EN), IC9.A2 (VIN_1), IC9.A3 (VIN_2), TP_VREG.TP

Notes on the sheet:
E-Paper Drive Circuit
Fuel Gauge
E-Paper Display Connector
Buttons
Haptic Driver
USB C Connector & ESD Protection
LiPo Charger
DC/DC
IMU
SWD

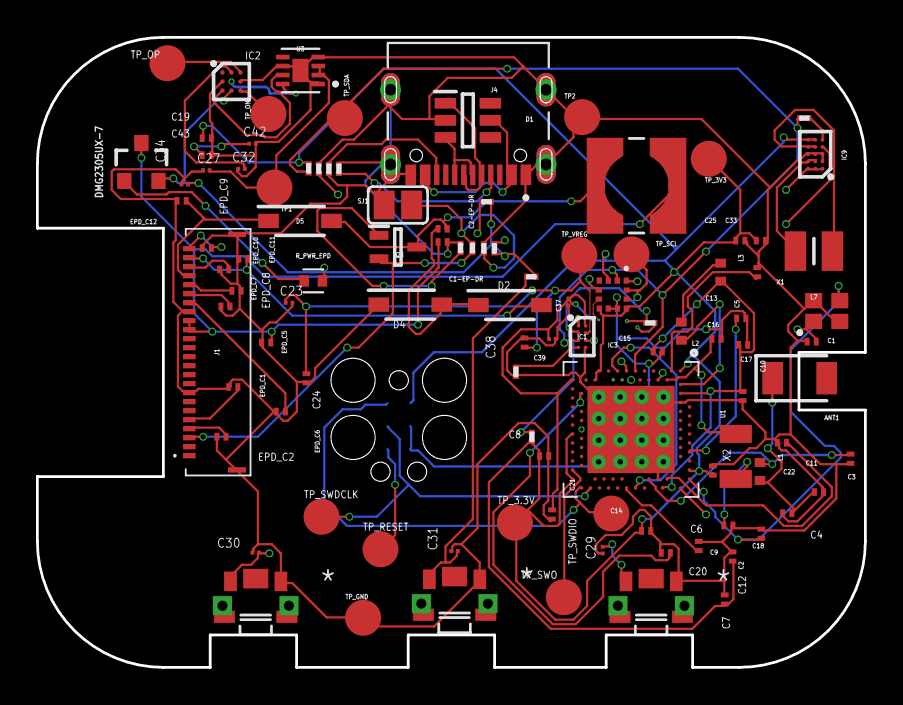
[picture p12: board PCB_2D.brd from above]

Board: 4 copper layers, 46.0 x 35.0 mm, 105 parts (1 on the bottom side), 67 nets.

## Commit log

2026-04-10 Add project files
    [Schema PCB.brd, Schematic.sch]
2026-04-19 Delete PCB 3d - randare.png
    Clean up non-compliant project files
2026-04-19 Delete PCB3D-Piesa.f3d
    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
2026-04-19 Delete Schema PCB.brd
    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
    [Schema PCB.brd]
2026-04-19 Delete Schematic.sch
    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
    [Schematic.sch]
2026-04-19 Add final project files: hardware, manufacturing, mechanical and images
    Added complete project structure:
    - Hardware: schematics and PCB design files
    - Manufacturing: gerbers, BOM and pick-and-place files
    - Mechanical: 3D assembly files and Fusion360 project
    - Images: final PCB and assembly renders
    - Updated README with full project documentation
    [PCB_2D.brd, Schematic_final.sch]

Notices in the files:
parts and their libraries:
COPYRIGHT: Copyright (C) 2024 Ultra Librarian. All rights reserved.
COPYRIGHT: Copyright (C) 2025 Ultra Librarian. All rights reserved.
